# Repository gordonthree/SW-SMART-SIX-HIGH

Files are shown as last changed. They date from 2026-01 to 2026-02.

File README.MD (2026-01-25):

# Smart Six-way High Side Switch Node
Compact power management board intended to control six high-side DC loads. The node provides current monitoring of each load, and the board total. Temperature and supply voltage are also monitored. This node works with other CAN-CTL modules using the robust CAN bus interface.

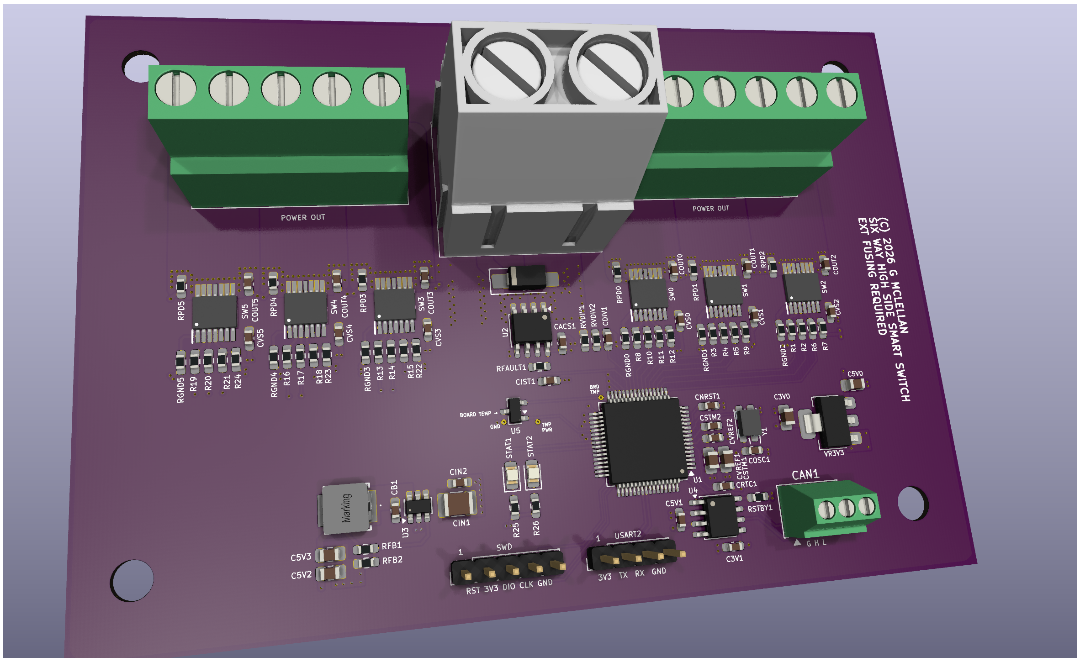
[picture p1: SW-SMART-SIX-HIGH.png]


* STM32G071 microcontroller with 64 pins and 256k flash
* Six Infineon BTS7002 Profet Smart Switches for high side loads; firmware limited to 15 amps each
* Allegro ACS712 on board to monitor total board current; firmware limited to 30 amps
* Microchip MCP2562 isolated CAN bus transceiver
* Microchip MCP9701 board mount temperature sensor
* Voltage divider to monitor supply voltage
* Each switch provides current monitoring and diagnostics
* Screw terminal block for CAN bus connection
* Screw terminal block for power-out, up to 12 AWG
* Heavy duty screw terminals for power in, up to 6 AWG cable
* Headers for SWD programming and USART2 serial port

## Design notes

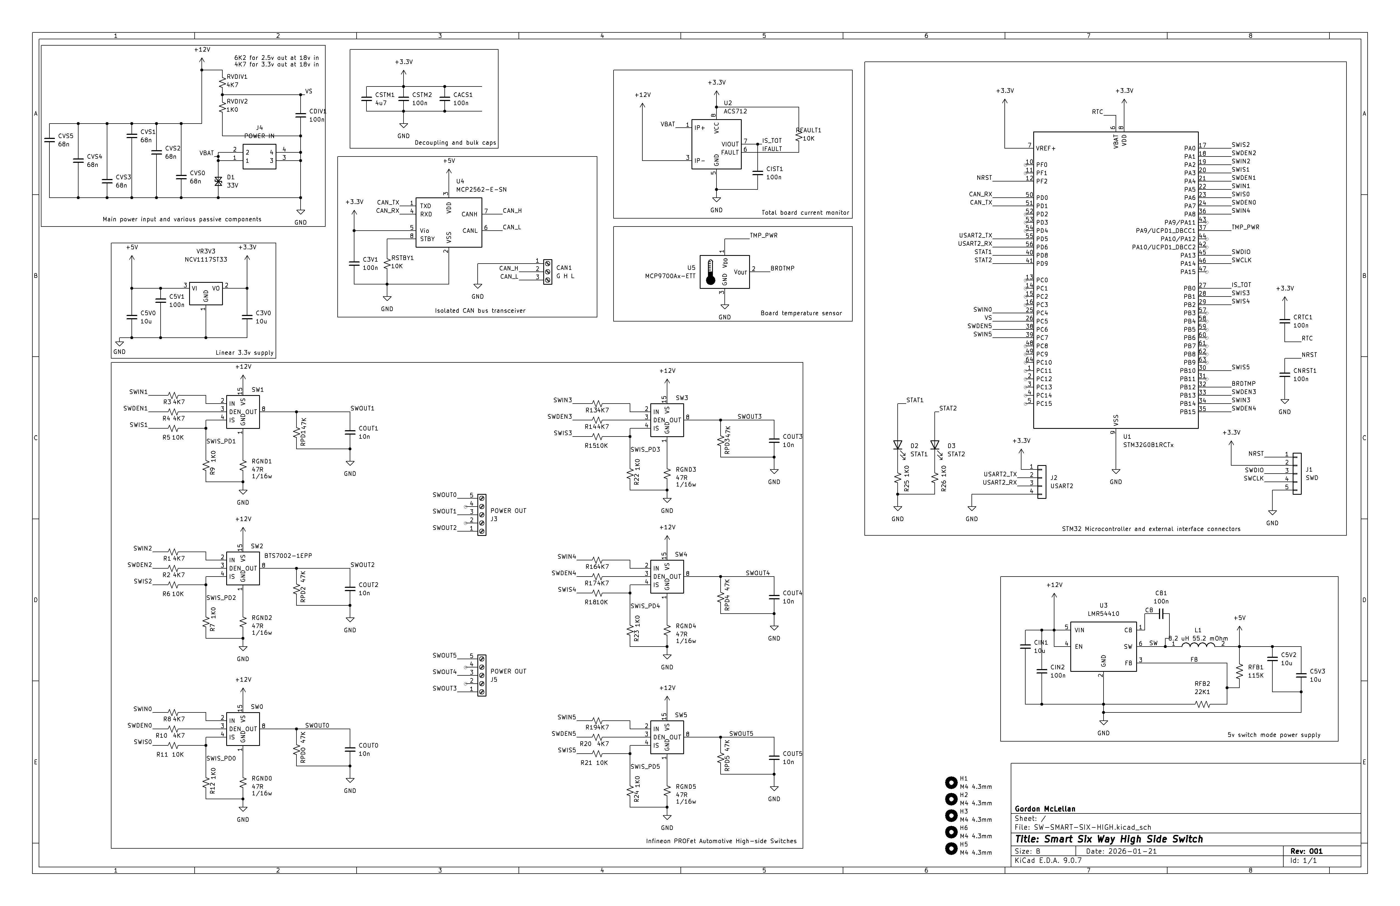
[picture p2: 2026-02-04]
sw-smart-six-high-sch.png

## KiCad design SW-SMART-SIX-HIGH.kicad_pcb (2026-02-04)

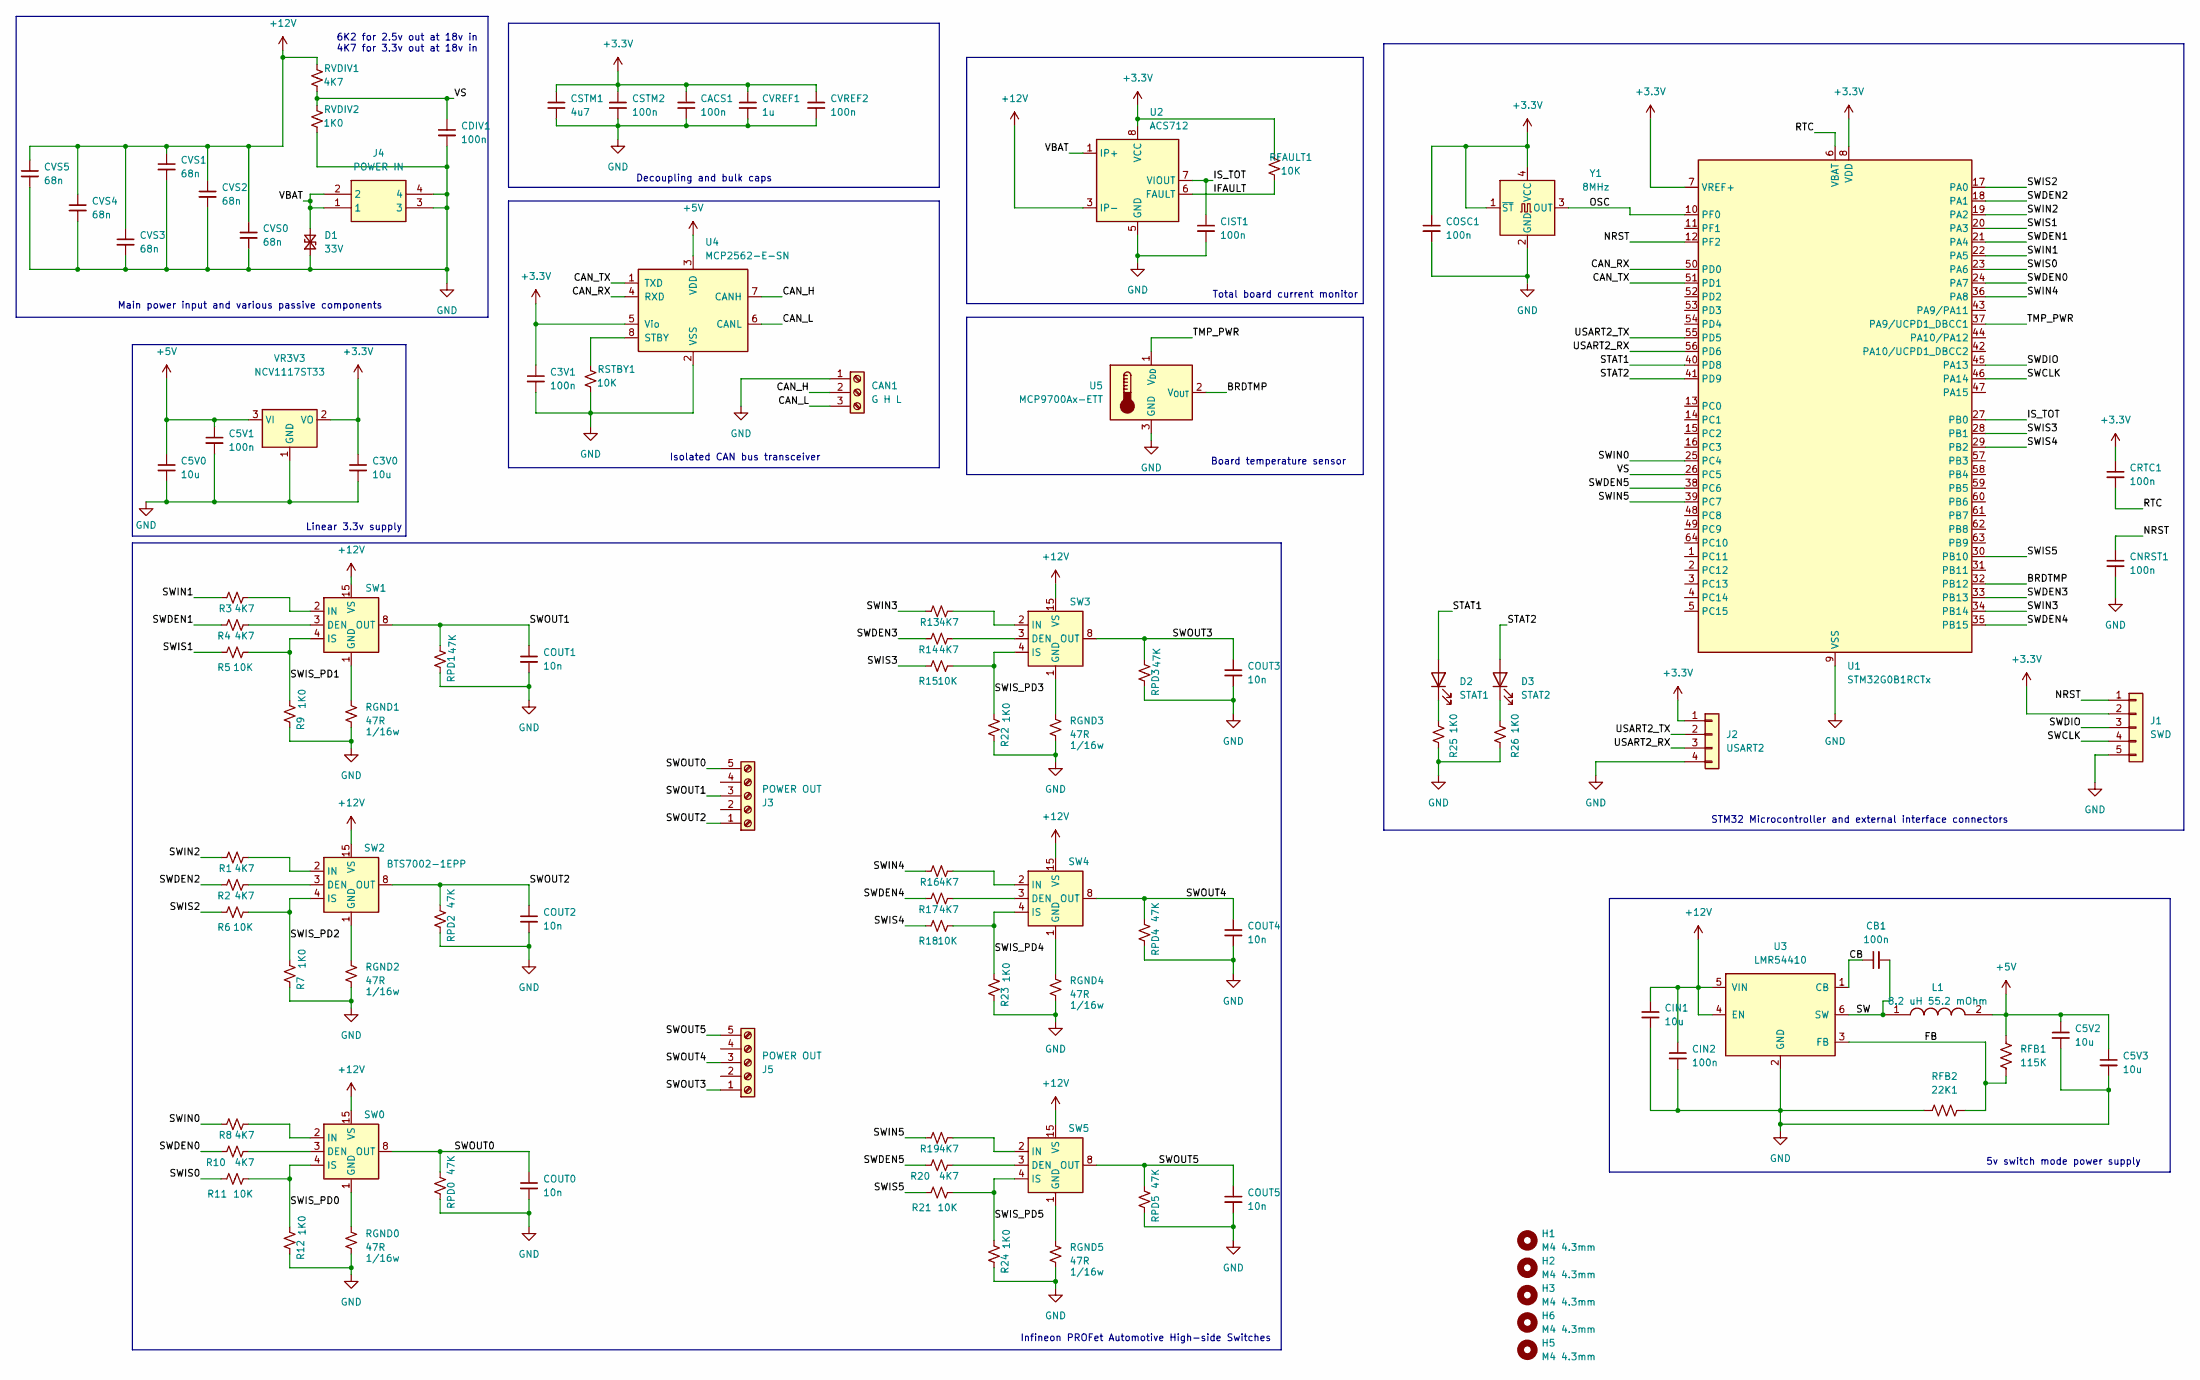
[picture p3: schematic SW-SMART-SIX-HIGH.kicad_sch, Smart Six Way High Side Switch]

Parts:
C3V0, C5V0, C5V2, C5V3: 10u; C_0805_2012Metric_Pad1.18x1.45mm_HandSolder
C3V1, C5V1: 100n; C_0603_1608Metric_Pad1.08x0.95mm_HandSolder
CACS1: 100n; C_0603_1608Metric_Pad1.08x0.95mm_HandSolder
CAN1: G H L; TerminalBlock_Phoenix_MPT-0,5-3-2.54_1x03_P2.54mm_Horizontal
CB1: 100n; C_0603_1608Metric_Pad1.08x0.95mm_HandSolder
CDIV1: 100n; C_0603_1608Metric_Pad1.08x0.95mm_HandSolder
CIN1: 10u; C_1210_3225Metric_Pad1.33x2.70mm_HandSolder
CIN2: 100n; C_0603_1608Metric_Pad1.08x0.95mm_HandSolder
CIST1: 100n; C_0603_1608Metric_Pad1.08x0.95mm_HandSolder
CNRST1: 100n; C_0603_1608Metric_Pad1.08x0.95mm_HandSolder
COSC1: 100n; C_0603_1608Metric_Pad1.08x0.95mm_HandSolder
COUT0, COUT1, COUT2, COUT3, COUT4, COUT5: 10n; C_0603_1608Metric_Pad1.08x0.95mm_HandSolder
CRTC1: 100n; C_0603_1608Metric_Pad1.08x0.95mm_HandSolder
CSTM1: 4u7; C_0805_2012Metric_Pad1.18x1.45mm_HandSolder
CSTM2: 100n; C_0603_1608Metric_Pad1.08x0.95mm_HandSolder
CVREF1: 1u; C_0805_2012Metric_Pad1.18x1.45mm_HandSolder
CVREF2: 100n; C_0603_1608Metric_Pad1.08x0.95mm_HandSolder
CVS0, CVS1, CVS2, CVS3, CVS4, CVS5: 68n; C_0603_1608Metric_Pad1.08x0.95mm_HandSolder
D1: 33V; D_SMA_Handsoldering
D2: STAT1; LED_0805_2012Metric_Pad1.15x1.40mm_HandSolder
D3: STAT2; LED_0805_2012Metric_Pad1.15x1.40mm_HandSolder
H1, H2, H3, H5, H6: M4 4.3mm; MountingHole_4.3mm_M4
J1: SWD; PinHeader_1x05_P2.54mm_Vertical
J2: USART2; PinHeader_1x04_P2.54mm_Vertical
J3, J5: POWER OUT; TerminalBlock_Phoenix_MKDS-3-5-5.08_1x05_P5.08mm_Horizontal
J4: POWER IN; VP0265840000G; Mouser Part Number 649-VP02658400J0G
L1: 8.2 uH 55.2 mOhm; SRP5030HMT2R2M; Mouser Part Number SRP5030HMT-8R2M
R1, R2, R3, R4, R8, R10, R13, R14, R16, R17, R19, R20: 4K7; R_0603_1608Metric_Pad0.98x0.95mm_HandSolder
R5, R6, R11, R15, R18, R21: 10K; R_0603_1608Metric_Pad0.98x0.95mm_HandSolder
R7, R9, R12, R22, R23, R24, R25, R26: 1K0; R_0603_1608Metric_Pad0.98x0.95mm_HandSolder
RFAULT1: 10K; R_0603_1608Metric_Pad0.98x0.95mm_HandSolder
RFB1: 115K; R_0603_1608Metric_Pad0.98x0.95mm_HandSolder
RFB2: 22K1; R_0603_1608Metric_Pad0.98x0.95mm_HandSolder
RGND0, RGND1, RGND2, RGND3, RGND4, RGND5: 47R; R_0603_1608Metric_Pad0.98x0.95mm_HandSolder
RPD0, RPD1, RPD2, RPD3, RPD4, RPD5: 47K; R_0603_1608Metric_Pad0.98x0.95mm_HandSolder
RSTBY1: 10K; R_0603_1608Metric_Pad0.98x0.95mm_HandSolder
RVDIV1: 4K7; R_0603_1608Metric_Pad0.98x0.95mm_HandSolder
RVDIV2: 1K0; R_0603_1608Metric_Pad0.98x0.95mm_HandSolder
SW0, SW1, SW2, SW3, SW4, SW5: BTS7002-1EPP; SOP65P600X115-15N
U1: STM32G0B1RCTx; LQFP-64_10x10mm_P0.5mm
U2: ACS712; SOIC-8_3.9x4.9mm_P1.27mm; Part Number ACS71240LLCBTR-050B3
U3: LMR54410; SOT-23-6
U4: MCP2562-E-SN; SOIC-8_3.9x4.9mm_P1.27mm
U5: MCP9700Ax-ETT; SOT-23
VR3V3: NCV1117ST33; SOT-223-3_TabPin2
Y1: 8MHz; Oscillator_SMD_EuroQuartz_XO32-4Pin_3.2x2.5mm_RotB_HandSold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

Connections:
+3.3V: C3V0.1, C3V1.1, CACS1.1, COSC1.1, CRTC1.1, CSTM1.1, CSTM2.1, CVREF1.1, CVREF2.1, J1.2, J2.1, RFAULT1.2, U1.7 (VREF+), U1.8 (VDD), U2.8 (VCC), U4.5 (Vio), VR3V3.2 (VO), Y1.1 (~ST), Y1.4 (VCC)
+5V: C5V0.1, C5V1.1, C5V2.1, C5V3.1, L1.2, RFB1.1, U4.3 (VDD), VR3V3.3 (VI)
+12V: CIN1.1, CIN2.1, CVS0.1, CVS1.1, CVS2.1, CVS3.1, CVS4.1, CVS5.1, RVDIV1.2, SW0.15 (VS), SW1.15 (VS), SW2.15 (VS), SW3.15 (VS), SW4.15 (VS), SW5.15 (VS), U2.3 (IP-), U2.4 (IP-), U3.4 (EN), U3.5 (VIN)
/BRDTMP: U1.32 (PB12), U5.2 (V_{OUT})
/CAN_H: CAN1.2, U4.7 (CANH)
/CAN_L: CAN1.3, U4.6 (CANL)
/CAN_RX: U1.50 (PD0), U4.4 (RXD)
/CAN_TX: U1.51 (PD1), U4.1 (TXD)
/CB: CB1.1, U3.1 (CB)
/FB: RFB1.2, RFB2.2, U3.3 (FB)
/IFAULT: RFAULT1.1, U2.6 (FAULT)
/IS_TOT: CIST1.1, U1.27 (PB0), U2.7 (VIOUT)
/NRST: CNRST1.1, J1.1, U1.12 (PF2)
/OSC: U1.10 (PF0), Y1.3 (OUT)
/RTC: CRTC1.2, U1.6 (VBAT)
/STAT1: D2.2 (A), U1.40 (PD8)
/STAT2: D3.2 (A), U1.41 (PD9)
/SW: CB1.2, L1.1, U3.6 (SW)
/SWCLK: J1.4, U1.46 (PA14)
/SWDEN0: R10.1, U1.24 (PA7)
/SWDEN1: R4.1, U1.21 (PA4)
/SWDEN2: R2.1, U1.18 (PA1)
/SWDEN3: R14.1, U1.33 (PB13)
/SWDEN4: R17.1, U1.35 (PB15)
/SWDEN5: R20.1, U1.38 (PC6)
/SWDIO: J1.3, U1.45 (PA13)
/SWIN0: R8.1, U1.25 (PC4)
/SWIN1: R3.1, U1.22 (PA5)
/SWIN2: R1.1, U1.19 (PA2)
/SWIN3: R13.1, U1.34 (PB14)
/SWIN4: R16.1, U1.36 (PA8)
/SWIN5: R19.1, U1.39 (PC7)
/SWIS0: R11.1, U1.23 (PA6)
/SWIS1: R5.1, U1.20 (PA3)
/SWIS2: R6.1, U1.17 (PA0)
/SWIS3: R15.1, U1.28 (PB1)
/SWIS4: R18.1, U1.29 (PB2)
/SWIS5: R21.1, U1.30 (PB10)
/SWIS_PD0: R11.2, R12.2, SW0.4 (IS)
/SWIS_PD1: R5.2, R9.2, SW1.4 (IS)
/SWIS_PD2: R6.2, R7.2, SW2.4 (IS)
/SWIS_PD3: R15.2, R22.2, SW3.4 (IS)
/SWIS_PD4: R18.2, R23.2, SW4.4 (IS)
/SWIS_PD5: R21.2, R24.2, SW5.4 (IS)
/SWOUT0: COUT0.1, J3.5, RPD0.2, SW0.8 (OUT), SW0.9 (OUT), SW0.10 (OUT), SW0.12 (OUT), SW0.13 (OUT), SW0.14 (OUT)
/SWOUT1: COUT1.1, J3.3, RPD1.2, SW1.8 (OUT), SW1.9 (OUT), SW1.10 (OUT), SW1.12 (OUT), SW1.13 (OUT), SW1.14 (OUT)
/SWOUT2: COUT2.1, J3.1, RPD2.2, SW2.8 (OUT), SW2.9 (OUT), SW2.10 (OUT), SW2.12 (OUT), SW2.13 (OUT), SW2.14 (OUT)
/SWOUT3: COUT3.1, J5.1, RPD3.2, SW3.8 (OUT), SW3.9 (OUT), SW3.10 (OUT), SW3.12 (OUT), SW3.13 (OUT), SW3.14 (OUT)
/SWOUT4: COUT4.1, J5.3, RPD4.2, SW4.8 (OUT), SW4.9 (OUT), SW4.10 (OUT), SW4.12 (OUT), SW4.13 (OUT), SW4.14 (OUT)
/SWOUT5: COUT5.1, J5.5, RPD5.2, SW5.8 (OUT), SW5.9 (OUT), SW5.10 (OUT), SW5.12 (OUT), SW5.13 (OUT), SW5.14 (OUT)
/TMP_PWR: U1.37 (PA9/UCPD1_DBCC1), U5.1 (V_{DD})
/USART2_RX: J2.3, U1.56 (PD6)
/USART2_TX: J2.2, U1.55 (PD5)
/VBAT: D1.2 (A2), J4.1, J4.2, U2.1 (IP+), U2.2 (IP+)
/VS: CDIV1.1, RVDIV1.1, RVDIV2.2, U1.26 (PC5)
GND: C3V0.2, C3V1.2, C5V0.2, C5V1.2, C5V2.2, C5V3.2, CACS1.2, CAN1.1, CDIV1.2, CIN1.2, CIN2.2, CIST1.2, CNRST1.2, COSC1.2, COUT0.2, COUT1.2, COUT2.2, COUT3.2, COUT4.2, COUT5.2, CSTM1.2, CSTM2.2, CVREF1.2, CVREF2.2, CVS0.2, CVS1.2, CVS2.2, CVS3.2, CVS4.2, CVS5.2, D1.1 (A1), J1.5, J2.4, J4.3, J4.4, R7.1, R9.1, R12.1, R22.1, R23.1, R24.1, R25.1, R26.1, RFB2.1, RGND0.2, RGND1.2, RGND2.2, RGND3.2, RGND4.2, RGND5.2, RPD0.1, RPD1.1, RPD2.1, RPD3.1, RPD4.1, RPD5.1, RSTBY1.1, RVDIV2.1, U1.9 (VSS), U2.5 (GND), U3.2 (GND), U4.2 (VSS), U5.3 (GND), VR3V3.1 (GND), Y1.2 (GND)
unnamed: D2.1 (K), R25.2
unnamed: D3.1 (K), R26.2
unnamed: R10.2, SW0.3 (DEN)
unnamed: RGND0.1, SW0.1 (GND)
unnamed: R8.2, SW0.2 (IN)
unnamed: R4.2, SW1.3 (DEN)
unnamed: RGND1.1, SW1.1 (GND)
unnamed: R3.2, SW1.2 (IN)
unnamed: R2.2, SW2.3 (DEN)
unnamed: RGND2.1, SW2.1 (GND)
unnamed: R1.2, SW2.2 (IN)
unnamed: R14.2, SW3.3 (DEN)
unnamed: RGND3.1, SW3.1 (GND)
unnamed: R13.2, SW3.2 (IN)
unnamed: R17.2, SW4.3 (DEN)
unnamed: RGND4.1, SW4.1 (GND)
unnamed: R16.2, SW4.2 (IN)
unnamed: R20.2, SW5.3 (DEN)
unnamed: RGND5.1, SW5.1 (GND)
unnamed: R19.2, SW5.2 (IN)
unnamed: RSTBY1.2, U4.8 (STBY)

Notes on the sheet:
Isolated CAN bus transceiver
6K2 for 2.5v out at 18v in 4K7 for 3.3v out at 18v in
Total board current monitor
Linear 3.3v supply
Main power input and various passive components
STM32 Microcontroller and external interface connectors
Infineon PROFet Automotive High-side Switches
Decoupling and bulk caps
5v switch mode power supply
Board temperature sensor

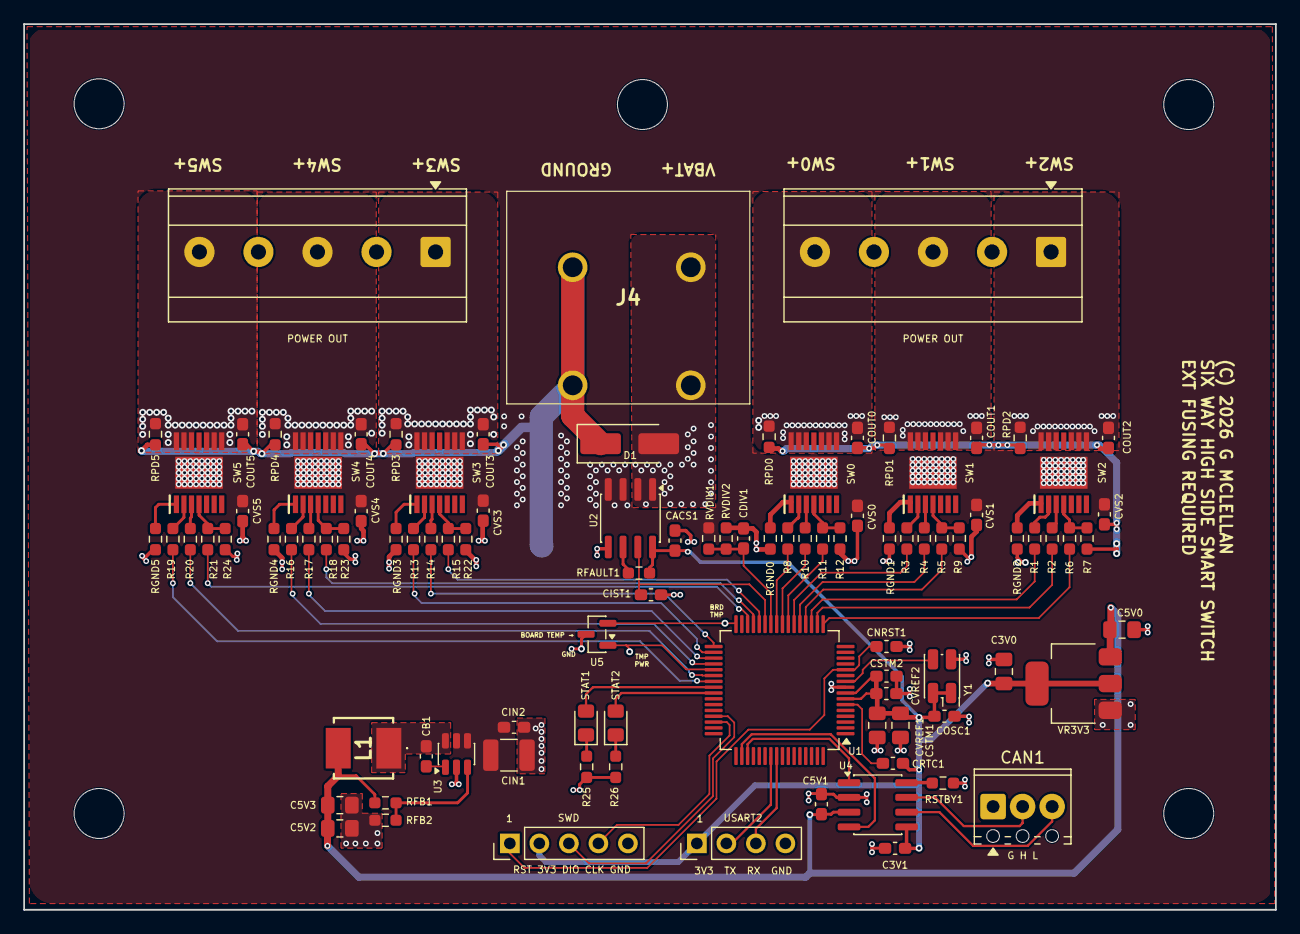
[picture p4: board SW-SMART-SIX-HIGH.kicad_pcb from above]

Board: 2 copper layers, 107.7 x 76.2 mm, 103 parts (0 on the bottom side), 77 nets.

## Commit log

2026-01-21 lots of work to do!
    [SW-SMART-SIX-HIGH.kicad_pcb, SW-SMART-SIX-HIGH.kicad_sch]
2026-01-21 added ACS712 to monitor total board current
    [SW-SMART-SIX-HIGH.kicad_sch]
2026-01-21 layout starting to take shape
    [SW-SMART-SIX-HIGH.kicad_pcb]
2026-01-22 swapped to a 48pin uC
    [SW-SMART-SIX-HIGH.kicad_sch]
2026-01-22 layout work continues
    [SW-SMART-SIX-HIGH.kicad_pcb]
2026-01-22 lots of work to do still
    [SW-SMART-SIX-HIGH.kicad_pcb, SW-SMART-SIX-HIGH.kicad_sch]
2026-01-22 making progress on layout and routing
    [SW-SMART-SIX-HIGH.kicad_pcb]
2026-01-22 I think I'm done adding components
    [SW-SMART-SIX-HIGH.kicad_sch]
2026-01-22 update to the 64pin micro
    [SW-SMART-SIX-HIGH.kicad_sch]
2026-01-22 great progress with routing so far
    [SW-SMART-SIX-HIGH.kicad_pcb, SW-SMART-SIX-HIGH.kicad_sch]
2026-01-22 signals routed, next is power
    [SW-SMART-SIX-HIGH.kicad_pcb, SW-SMART-SIX-HIGH.kicad_sch]
2026-01-22 everything is routed, drc passed
    [SW-SMART-SIX-HIGH.kicad_pcb]
2026-01-22 Schematic cleanup and documentation
    [SW-SMART-SIX-HIGH.kicad_sch]
2026-01-22 fine tune a few things
    [SW-SMART-SIX-HIGH.kicad_pcb]
2026-01-22 fix a few issues that cropped up
    [SW-SMART-SIX-HIGH.kicad_pcb, SW-SMART-SIX-HIGH.kicad_sch]
2026-01-23 added dedicated board temperature sensor
    [SW-SMART-SIX-HIGH.kicad_pcb, SW-SMART-SIX-HIGH.kicad_sch]
2026-01-23 added dedicated board temp sensor and some silkscreen tweaks
    [SW-SMART-SIX-HIGH.kicad_pcb]
2026-01-23 added board temp sensor
    [SW-SMART-SIX-HIGH.kicad_sch]
2026-01-25 changed can connector wiring and footprint size
    [SW-SMART-SIX-HIGH.kicad_pcb]
2026-01-25 updated can bus connector footprint
    [SW-SMART-SIX-HIGH.kicad_sch]
2026-01-27 added recommended mcu vref capacitors
    [SW-SMART-SIX-HIGH.kicad_pcb, SW-SMART-SIX-HIGH.kicad_sch]
2026-01-27 adjusted grounding and copper pour dimensions
    [SW-SMART-SIX-HIGH.kicad_pcb]
2026-02-02 added crystal osc
    [SW-SMART-SIX-HIGH.kicad_pcb, SW-SMART-SIX-HIGH.kicad_sch]
2026-02-04 outdated schematic pdf

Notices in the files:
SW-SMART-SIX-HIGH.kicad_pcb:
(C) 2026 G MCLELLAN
